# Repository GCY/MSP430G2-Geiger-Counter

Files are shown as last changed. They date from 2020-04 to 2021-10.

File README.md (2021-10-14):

# MSP430G2-Geiger-Counter

This device is Geiger-Muller Counter ,and True Random Number Generator(TRNG) uses radioactive isotopes.
</br>

Audi R8 (https://youtu.be/-gwNQ9MdoDw)

## Features

- [x] Radiation Detection - CPS, CPM, uSv/h, mSv/Y
- [x] Temperature - degree Celsius (°C)
- [x] True Random Number Generator - Serial Port Output 8bit TRNG





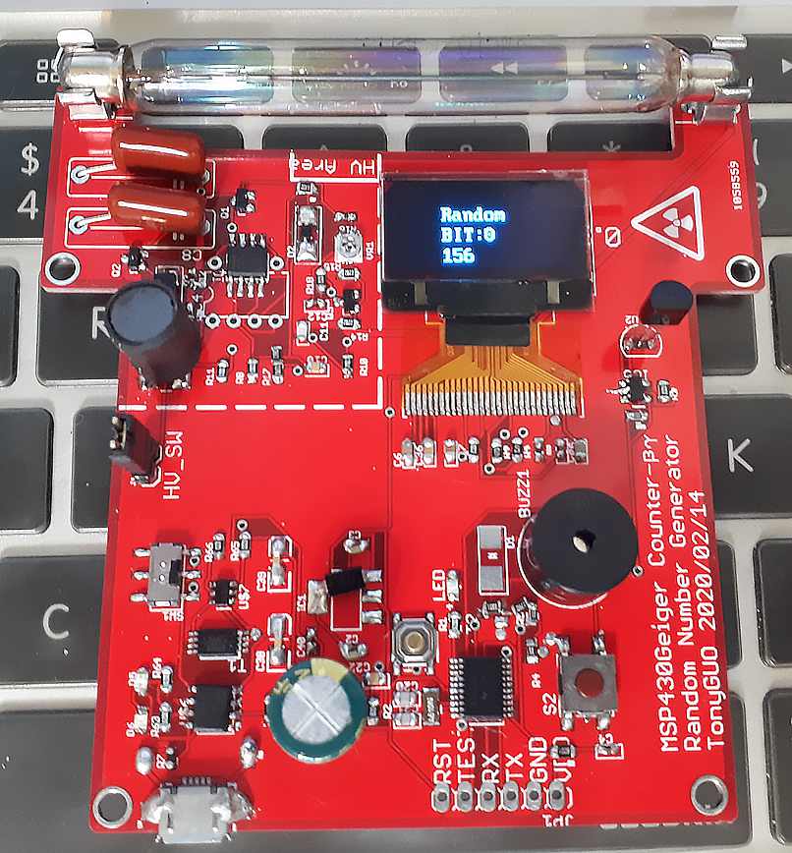
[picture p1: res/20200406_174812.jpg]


## Hardware

### Key Component List
- Geiger-Muller Tube - J321βγ, M4011, SBM-20...etc
- MSP430G2433 or MSP430G2553
- TLC555 (CMOS 555, DIP or SMD)
- TMP35 (Operate Voltage 3.3v)
- Fuse Holder on PCB for T5x20 Size * 2

### Configure

- J1 - CMOS555 4.2v power supply.
- VR1 - Adjust High-Voltage output 180VDC~500VDC, DMM setting 1000VDC internal resistance = 10M, if you measure tube voltage around 250VDC you're doing fine(real voltage 400VDC).
- IC1 - if this is use LDO, your temperature sensor power supply voltage = 2.9v-3v(TMP35), use forward voltage(VF) 0.5v diode,  temperature sensor power supply voltage = 3.7v-4v(LM35).

</br>

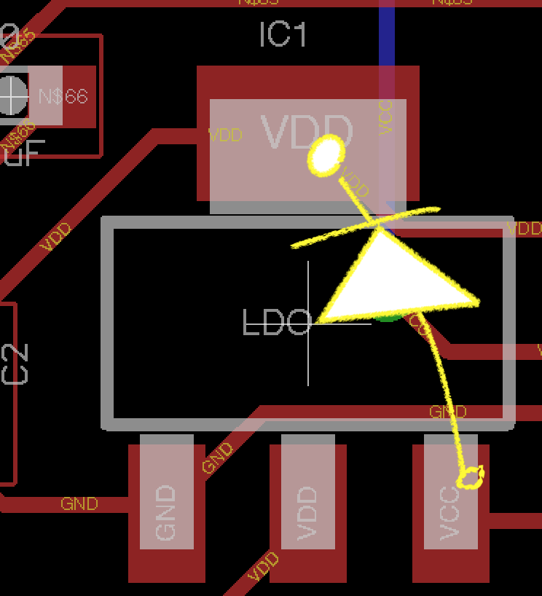
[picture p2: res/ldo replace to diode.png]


### Light Sensitive Problem (J321βγ, M4011)
[Reference This Discussion](http://www.gqelectronicsllc.com/forum/topic.asp?TOPIC_ID=4540)

</br>

For J321βγ, it doesn't happen often, I guess that's about wavelength of light.

## Firmware

### Build and Burn The .hex file
- Install Energia 1.6.10E18
- Select board -> MSP430G2553
- Open MSP430Geiger.ino
- Connect Debugger BSL to MSP430Geiger
- Upload
- Done

### Key Parameters

How to calculate calibration factor? Reference [Method1,2,3,4](https://sites.google.com/site/diygeigercounter/technical/gm-tubes-supported?authuser=0 ) (SBM-20 = 175, M4011 or J321βγ = 153.8)
</br>
<pre><code>
const float CPM2uSv = 153.8f; //CPM to uSv/h conversion rate
</code></pre>

</br>
R19, R20 is 10k and 33k, LM321 gain = 1+(33k/10k) = 4.3, so original temperature voltage: temp_vol = (ADC/4.3) * (3.3/1024), every 10mV(TMP35, LM35) = 1°C, temperature = temp_vol / 0.01 °C.
<pre><code>
const float TEMPERATURE_GAIN = 1.0f + 3.3f; // 1+ (33k/10k)
const float ADC2VOL = (3.3f/1024.0f);  // 3.3v/10bit
</code></pre>

### Radiation Measurements
If detected ionizing radiation MSP430G4 P1_4 interrupt count += 1.
</br>
CPM_TIME_PERIOD 20-second sampling-rate for count-per-minute calculate, CPM = 60sec/20sec * count;
<pre><code>
const unsigned long CPM_TIME_PERIOD = 20;
</code></pre>
Next, converting CPM to a Dose Unit.
<pre><code>
uSv/h = CPM / CPM2uSv(153.8);
mSv/Y = uSv/h * 24(Day-Hour) * 365(Year-Day)
</code></pre>
The worldwide average natural dose to humans is about 2.4 mSv/Y.

### Geiger Counter TRNG Algorithm

Calculate pulse-to-pulse time period of every three counts, if (C2-C1) > (C3-C2) output current bit 0 value, (C2-C1) <= (C3-C2) output current bit 1 value, this process is physically random.

<pre><code>
/* pseudo code */
pulse_diff_time_array[3] = {C1,C2,C3};

T1 = C2-C1;
T2 = C3-C2;

if(T1 > T2){
  random_number |= (0 <<= random_number_size);
}
if(T1 <= T2){
  random_number |= (1 <<= random_number_size);
}
++random_number_size;

if(random_number_size == 8){
  Serial Output random_number;
  random_number = 0;
  random_number_size = 0;
}

</code></pre>
</br>

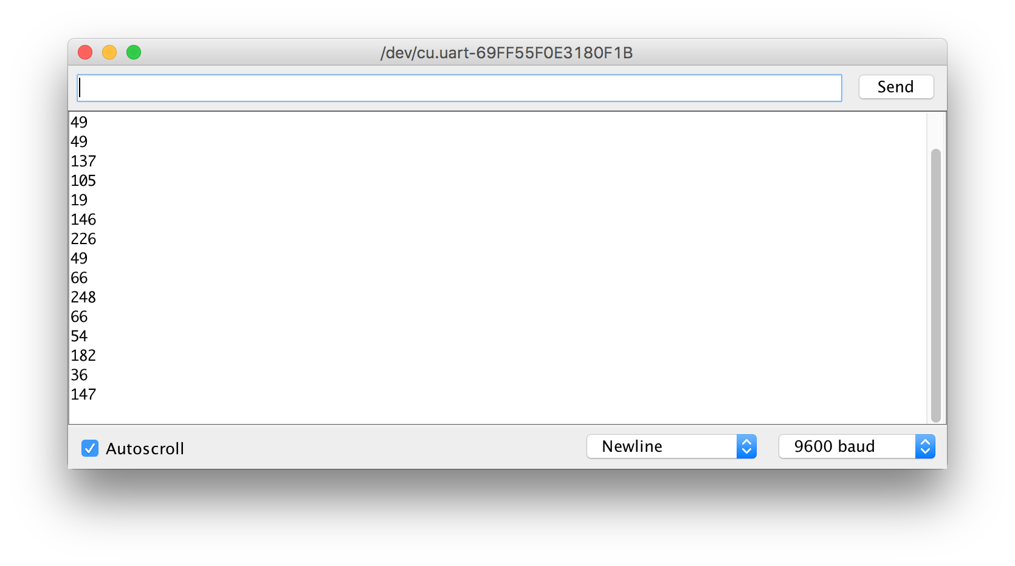
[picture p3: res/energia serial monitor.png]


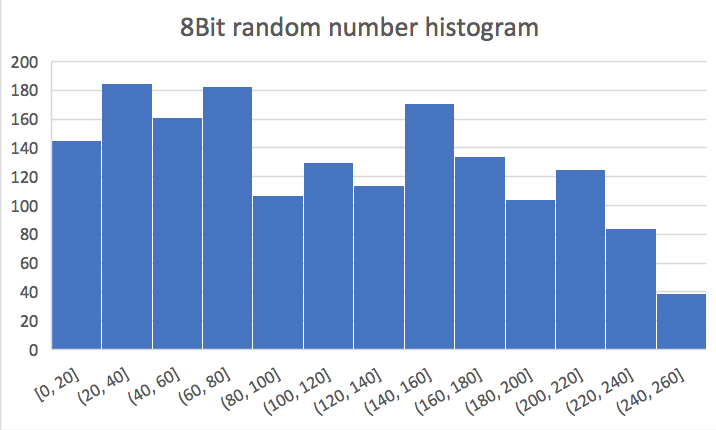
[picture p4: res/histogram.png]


### Encrypt Software Demo

## Reference

- [DIYGeiger](https://sites.google.com/site/diygeigercounter)
- [Geiger Counter WiKi](https://en.wikipedia.org/wiki/Geiger_counter)
- [Hardware Random Number Generator](https://en.wikipedia.org/wiki/Hardware_random_number_generator)

LICENSE
-------

MIT License

Copyright (c) 2020 Tony Guo https://github.com/GCY

Permission is hereby granted, free of charge, to any person obtaining a copy
of this software and associated documentation files (the "Software"), to deal
in the Software without restriction, including without limitation the rights
to use, copy, modify, merge, publish, distribute, sublicense, and/or sell
copies of the Software, and to permit persons to whom the Software is
furnished to do so, subject to the following conditions:

The above copyright notice and this permission notice shall be included in all
copies or substantial portions of the Software.

THE SOFTWARE IS PROVIDED "AS IS", WITHOUT WARRANTY OF ANY KIND, EXPRESS OR
IMPLIED, INCLUDING BUT NOT LIMITED TO THE WARRANTIES OF MERCHANTABILITY,
FITNESS FOR A PARTICULAR PURPOSE AND NONINFRINGEMENT. IN NO EVENT SHALL THE
AUTHORS OR COPYRIGHT HOLDERS BE LIABLE FOR ANY CLAIM, DAMAGES OR OTHER
LIABILITY, WHETHER IN AN ACTION OF CONTRACT, TORT OR OTHERWISE, ARISING FROM,
OUT OF OR IN CONNECTION WITH THE SOFTWARE OR THE USE OR OTHER DEALINGS IN THE
SOFTWARE.

OSHW Certification
-------

https://certification.oshwa.org/tw000004.html

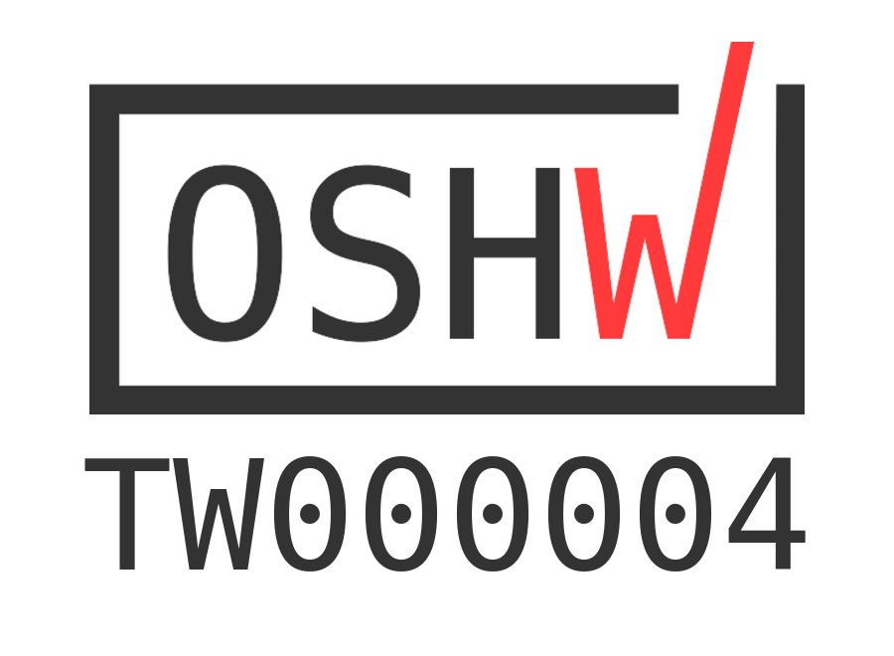
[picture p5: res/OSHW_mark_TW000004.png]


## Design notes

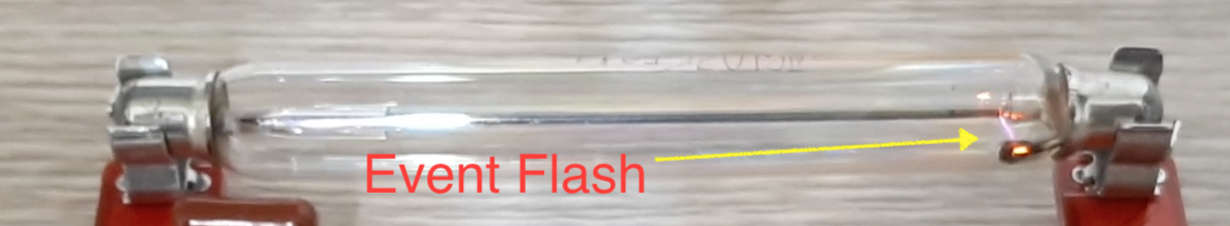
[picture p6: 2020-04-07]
res/geiger-muller tube flash.png

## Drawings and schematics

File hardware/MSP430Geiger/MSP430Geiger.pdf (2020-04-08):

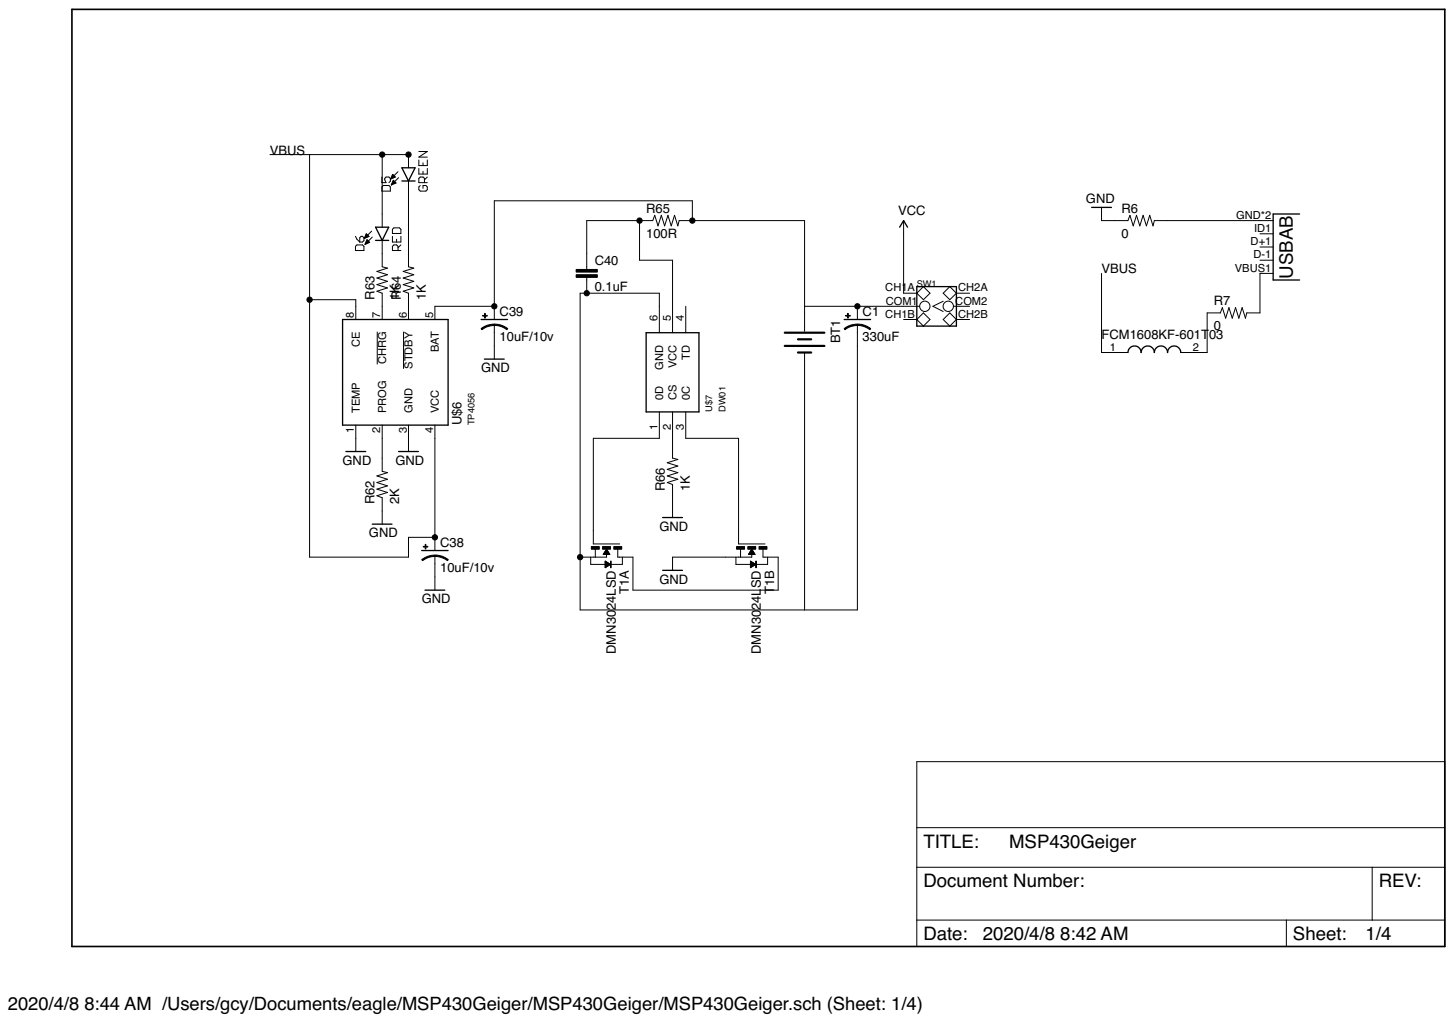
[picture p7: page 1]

Document Number: | REV:

Date: 2020/4/8 8:42 AM | Sheet: 1/4

2020/4/8 8:44 AM /Users/gcy/Documents/eagle/MSP430Geiger/MSP430Geiger/MSP430Geiger.sch (Sheet: 1/4)

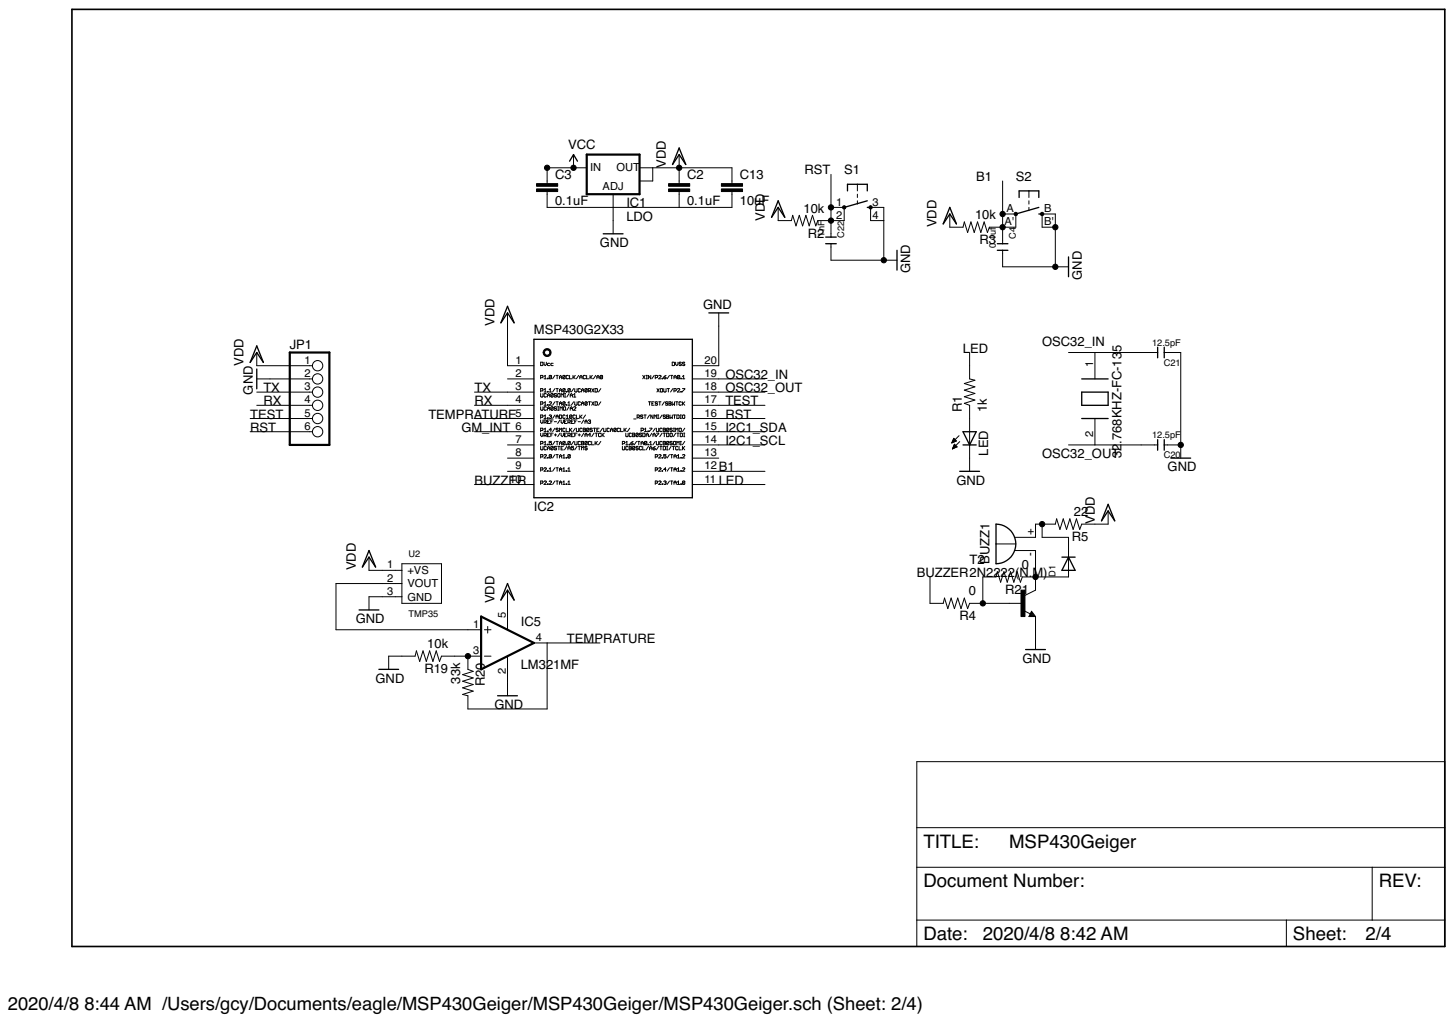
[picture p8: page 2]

Document Number: | REV:

Date: 2020/4/8 8:42 AM | Sheet: 2/4

2020/4/8 8:44 AM /Users/gcy/Documents/eagle/MSP430Geiger/MSP430Geiger/MSP430Geiger.sch (Sheet: 2/4)

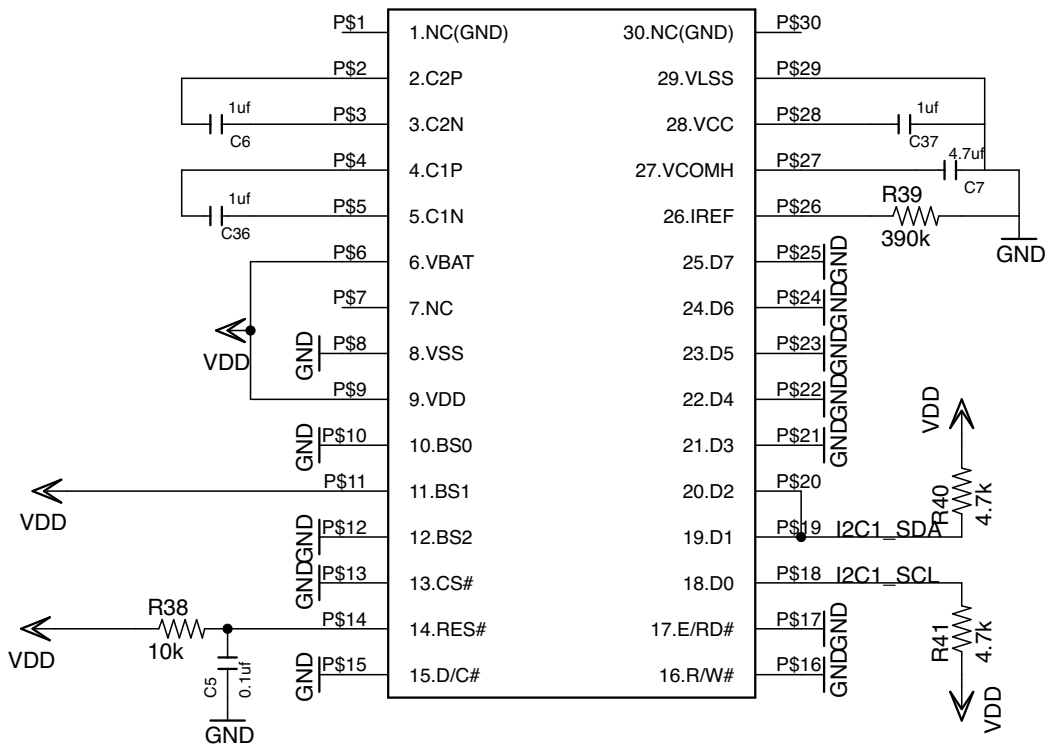
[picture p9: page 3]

GND GND GND GND GND

Document Number: | REV:

Date: 2020/4/8 8:42 AM | Sheet: 3/4

2020/4/8 8:44 AM /Users/gcy/Documents/eagle/MSP430Geiger/MSP430Geiger/MSP430Geiger.sch (Sheet: 3/4)

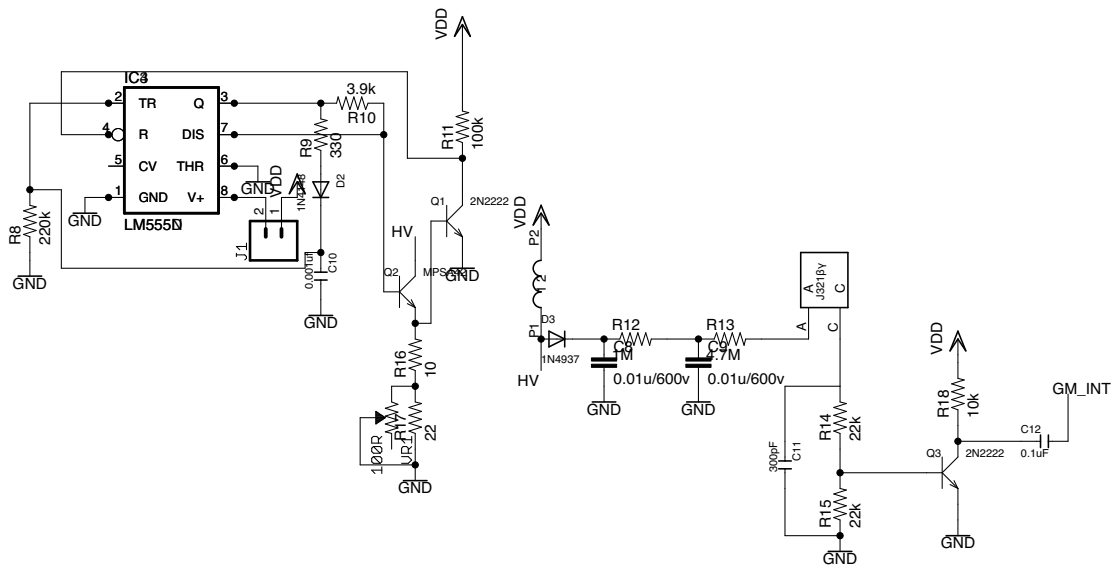
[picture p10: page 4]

Document Number: | REV:

Date: 2020/4/8 8:42 AM | Sheet: 4/4

2020/4/8 8:44 AM /Users/gcy/Documents/eagle/MSP430Geiger/MSP430Geiger/MSP430Geiger.sch (Sheet: 4/4)

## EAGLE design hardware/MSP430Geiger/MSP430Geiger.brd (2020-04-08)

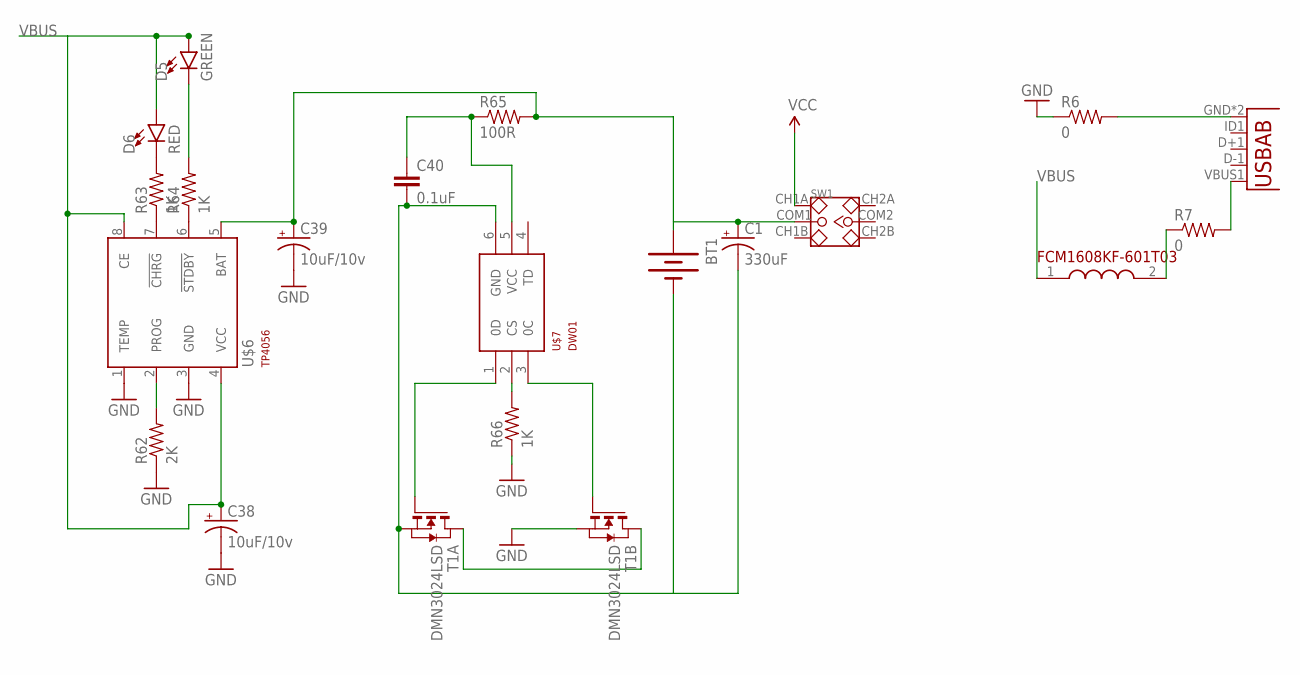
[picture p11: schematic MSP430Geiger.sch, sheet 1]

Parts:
BT1: BATTERYLIPO-TABS; LIPO-110-TABS
C1: 330uF; E3,5-8
C38, C39: 10uF/10v; EIA3216-KIT
C40: 0.1uF; 0603-CAP
D5: GREEN; LED-0603
D6: RED; LED-0603
R6, R7: 0; 0805
R62: 2K; 0603-RES
R63, R64, R66: 1K; 0603-RES
R65: 100R; 0603-RES
SW1: SMD-TOGGLE-SWITCH-2CH(2X3P-7X3.5MM); SW6-2.54-SMD-7.0X3.5X1.5MM
T1: DMN3024LSD; TSSOP-8
U1: USB""; USB-MICRO-SMD
U$4: FCM1608KF-601T03
U$6: TP4056; SOT23-8
U$7: DW01; SOT23-6

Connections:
GND: C38.C (-), C39.C (-), R6.1, R62.1, R66.1, T1.6 (S), T1.7 (S), U$6.1 (TEMP), U$6.3 (GND); also elsewhere on the board
unnamed: R7.2, U1.VBUS1 (VBUS)
unnamed: BT1.+, C1.+, C39.A (+), R65.2, SW1.COM1, U$6.5 (BAT)
unnamed: R7.1, U$4.2 (2.OUT)
unnamed: R6.2, U1.GND, U1.GND1 (GND)
unnamed: R62.2, U$6.2 (PROG)
unnamed: R63.1, U$6.7 (!CHRG)
unnamed: R64.1, U$6.6 (!STDBY)
unnamed: D6.C, R63.2
unnamed: D5.C, R64.2
unnamed: C40.1, R65.1, U$7.5 (VCC)
unnamed: BT1.-, C1.-, C40.2, T1.2 (S), T1.3 (S), U$7.6 (GND)
unnamed: T1.4 (G), U$7.1 (0D)
unnamed: R66.2, U$7.2 (CS)
unnamed: T1.1 (D), T1.8 (D)
unnamed: T1.5 (G), U$7.3 (0C)
VBUS: C38.A (+), D5.A, D6.A, U$4.1 (1.IN), U$6.4 (VCC), U$6.8 (CE)
VCC: SW1.CH1A; also elsewhere on the board

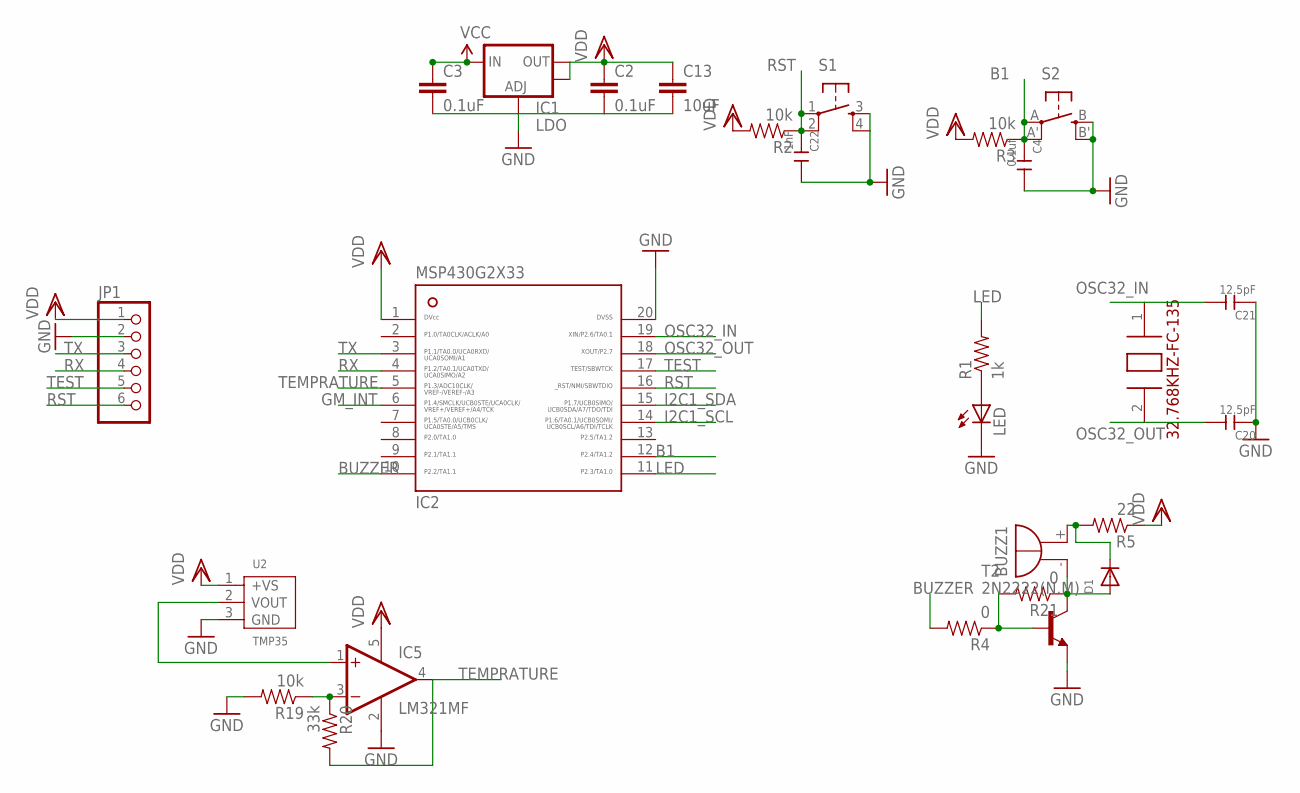
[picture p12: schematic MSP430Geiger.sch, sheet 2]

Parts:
BUZZ1: F/QMBIII
C2, C3: 0.1uF; 0603-CAP
C4: 0.1uf; C0603
C13: 10uF; 0603-CAP
C20, C21: 12.5pF; C0603
C22: 1nF; C0603
D1: DIODESMA; SMADIODE
IC1: LDO; SOT223
IC2: MSP430; PW20
IC5: LM321MF; SOT23-5
JP1: PINHD-1X6; 1X06
LED: LEDCHIP-LED0805; CHIP-LED0805
R1: 1k; 0805
R2, R3: 10k; 0603
R4, R21: 0; 0805
R5: 22; 0805
R19: 10k; 0805
R20: 33k; 0805
S1: TAC_SWITCHSMD; TACTILE_SWITCH_SMD
S2: SPST_TACT-EVQQ2; EVQ-Q2
T2: 2N2222(N.M); SOT23-EBC
U2: TMP35; TO-92-3
U$8: 32.768KHZ-FC-135

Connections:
B1: C4.1, IC2.12, R3.1, S2.A, S2.A' (P1)
BUZZER: IC2.10, R4.2
GM_INT: IC2.6; also elsewhere on the board
GND: C2.2, C3.2, C4.2, C13.2, C20.1, C21.1, C22.2, IC1.1 (ADJ), IC2.20, IC5.2 (V-), JP1.2, LED.C, R19.2, S1.3, S1.4, S2.B (S), S2.B' (S1), T2.E, U2.3 (GND); also elsewhere on the board
I2C1_SCL: IC2.14; also elsewhere on the board
I2C1_SDA: IC2.15; also elsewhere on the board
LED: IC2.11, R1.2
unnamed: R4.1, R21.2, T2.B
unnamed: LED.A, R1.1
unnamed: BUZZ1.- (+), D1.A, R21.1, T2.C
unnamed: BUZZ1.+ (-), D1.C, R5.2
unnamed: IC5.3 (-IN), R19.1, R20.1
unnamed: IC5.1 (+IN), U2.2 (VOUT)
OSC32_IN: C21.2, IC2.19, U$8.1 (1.XIN)
OSC32_OUT: C20.2, IC2.18, U$8.2 (2.XIN)
RST: C22.1, IC2.16, JP1.6, R2.1, S1.1, S1.2
RX: IC2.4, JP1.4
TEMPRATURE: IC2.5, IC5.4 (OUT), R20.2
TEST: IC2.17, JP1.5
TX: IC2.3, JP1.3
VCC: C3.1, IC1.3 (IN); also elsewhere on the board
VDD: C2.1, C13.1, IC1.2 (OUT), IC1.4 (OUT), IC2.1, IC5.5 (V+), JP1.1, R2.2, R3.2, R5.1, U2.1 (+VS); also elsewhere on the board

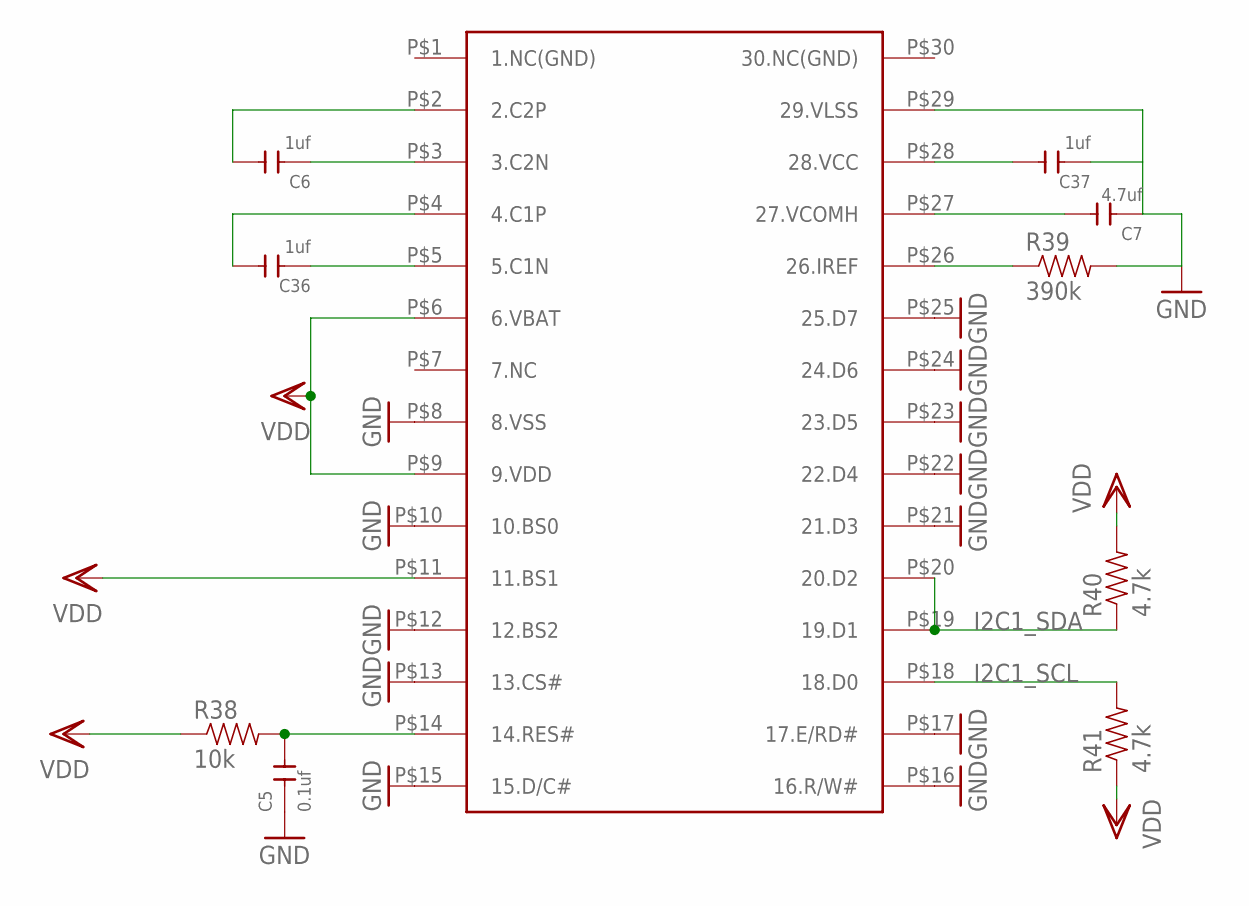
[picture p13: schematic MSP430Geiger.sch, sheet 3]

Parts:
C5: 0.1uf; C0603
C6, C36, C37: 1uf; C0603
C7: 4.7uf; C0603
R38: 10k; 0603
R39: 390k; 0603
R40, R41: 4.7k; 0603
U$18: ER-OLED0.96

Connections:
GND: C5.1, C7.1, C37.1, R39.2, U$18.P$8 (8.VSS), U$18.P$10 (10.BS0), U$18.P$12 (12.BS2), U$18.P$13 (13.CS#), U$18.P$15 (15.D/C#), U$18.P$16 (16.R/W#), U$18.P$17 (17.E/RD#), U$18.P$21 (21.D3), U$18.P$22 (22.D4), U$18.P$23 (23.D5), U$18.P$24 (24.D6), U$18.P$25 (25.D7), U$18.P$29 (29.VLSS); also elsewhere on the board
I2C1_SCL: R41.2, U$18.P$18 (18.D0); also elsewhere on the board
I2C1_SDA: R40.1, U$18.P$19 (19.D1), U$18.P$20 (20.D2); also elsewhere on the board
unnamed: C5.2, R38.2, U$18.P$14 (14.RES#)
unnamed: C6.1, U$18.P$3 (3.C2N)
unnamed: C36.1, U$18.P$5 (5.C1N)
unnamed: C6.2, U$18.P$2 (2.C2P)
unnamed: C36.2, U$18.P$4 (4.C1P)
unnamed: R39.1, U$18.P$26 (26.IREF)
unnamed: C7.2, U$18.P$27 (27.VCOMH)
unnamed: C37.2, U$18.P$28 (28.VCC)
VDD: R38.1, R40.2, R41.1, U$18.P$6 (6.VBAT), U$18.P$9 (9.VDD), U$18.P$11 (11.BS1); also elsewhere on the board

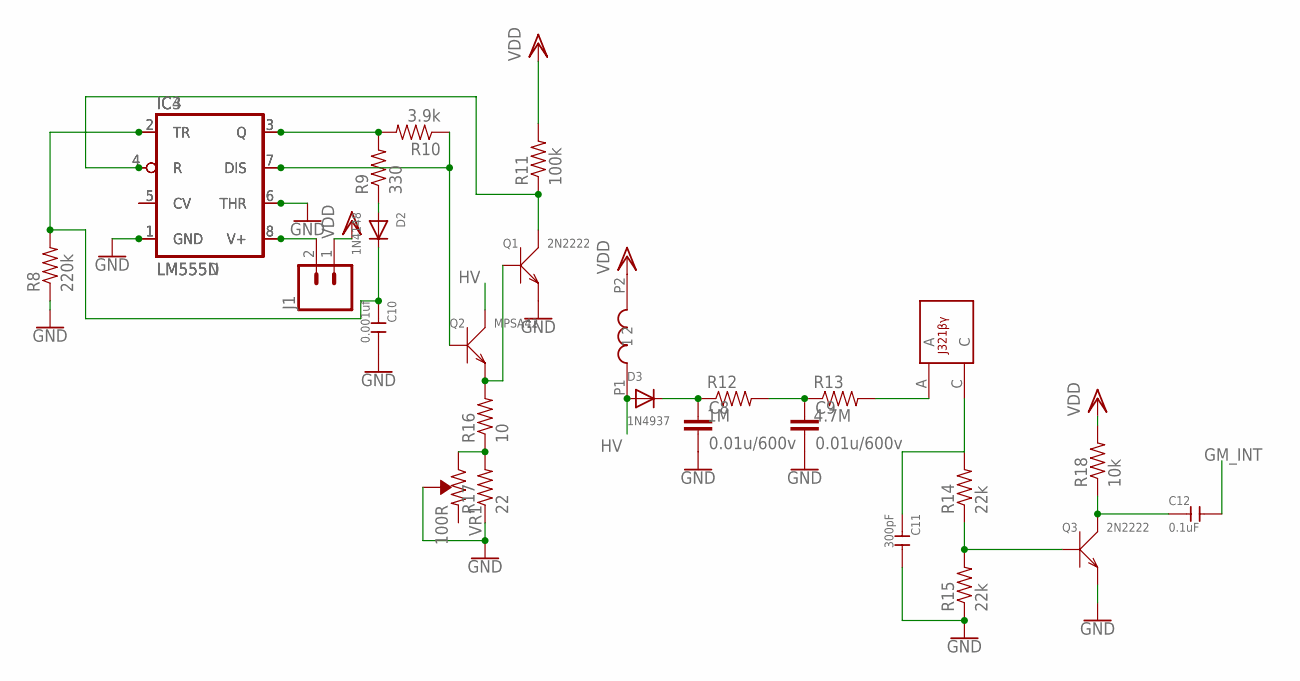
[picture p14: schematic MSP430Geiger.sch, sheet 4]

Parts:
C8, C9: 0.01u/600v; C15B5
C10: 0.001uf; C0603
C11: 300pF; C0603
C12: 0.1uF; C0603
D2: 1N4148; SMADIODE
D3: 1N4937; SMADIODE
IC3: LM555D; SO08
IC4: LM555N; DIL08-ROUND
J1: CONN_02; 1X02
Q1, Q3: 2N2222; SOT-23
Q2: MPSA42; SOT-23
R8: 220k; 0603
R9: 330; 0603
R10: 3.9k; 0603
R11: 100k; 0603
R12: 1M; 0603
R13: 4.7M; 0603
R14, R15: 22k; 0603
R16: 10; 0603
R17: 22; 0603
R18: 10k; 0603
U$1: J321βγ
U$2: 10mF; CD54
VR1: 100R; TRIMPOT-SMD-3MM-CLOSED

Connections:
GM_INT: C12.2; also elsewhere on the board
GND: C8.2, C9.2, C10.2, C11.2, IC3.1 (GND), IC3.6 (THR), IC4.1 (GND), IC4.6 (THR), Q1.2 (E), Q3.2 (E), R8.1, R15.1, R17.1, VR1.2 (WIPER); also elsewhere on the board
HV: D3.A, Q2.3 (C), U$2.P1 (1)
unnamed: IC3.3 (Q), IC4.3 (Q), R9.2, R10.2
unnamed: D2.A, R9.1
unnamed: IC3.7 (DIS), IC4.7 (DIS), Q2.1 (B), R10.1
unnamed: C10.1, D2.C, IC3.2 (TR), IC4.2 (TR), R8.2
unnamed: IC3.4 (R), IC4.4 (R), Q1.3 (C), R11.1
unnamed: Q1.1 (B), Q2.2 (E), R16.2
unnamed: C8.1, D3.C, R12.1
unnamed: C9.1, R12.2, R13.1
unnamed: R16.1, R17.2, VR1.3 (CW)
unnamed: IC3.5 (CV), IC4.5 (CV)
unnamed: R13.2, U$1.A
unnamed: C11.1, R14.2, U$1.C
unnamed: Q3.1 (B), R14.1, R15.2
unnamed: IC3.8 (V+), IC4.8 (V+), J1.2
unnamed: C12.1, Q3.3 (C), R18.1
VDD: J1.1, R11.2, R18.2, U$2.P2 (2); also elsewhere on the board

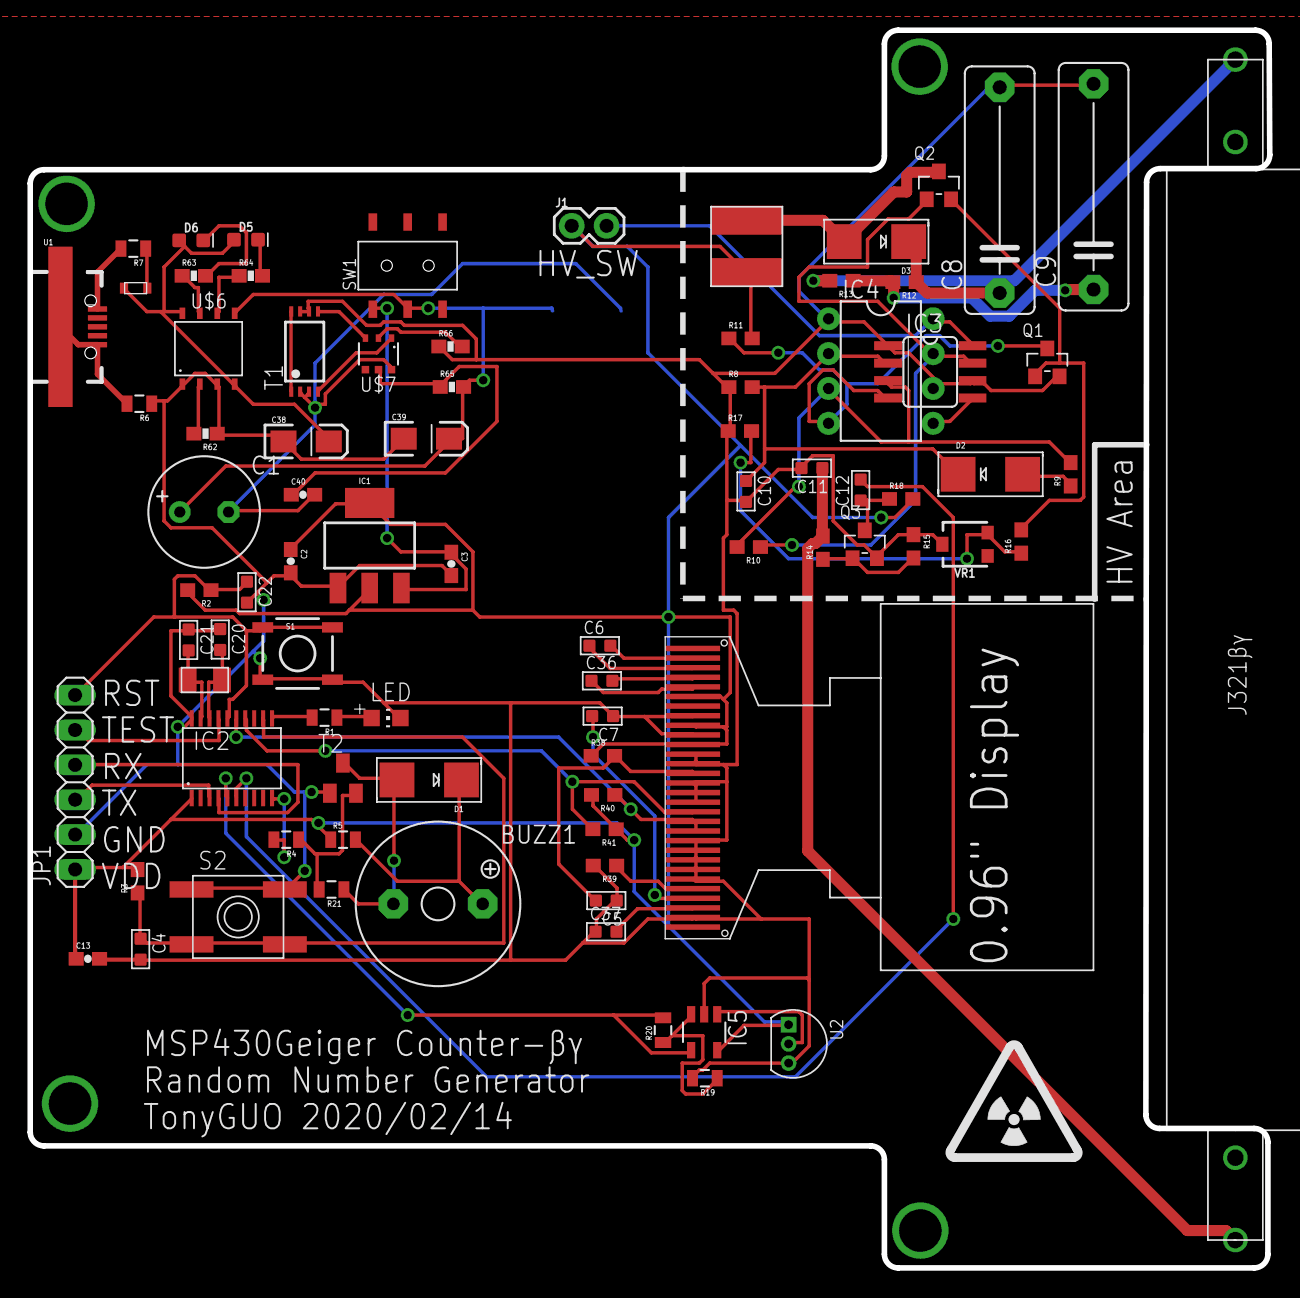
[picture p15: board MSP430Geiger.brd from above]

Board: 2 copper layers, 90.3 x 90.2 mm, 85 parts (1 on the bottom side), 62 nets.

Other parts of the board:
U$3: RADIOACTIVE_10.00

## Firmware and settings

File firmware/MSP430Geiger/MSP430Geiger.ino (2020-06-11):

#include "ASCII_CODE_8X16_5X8_VERTICAL.H"

#include <Wire.h>

#define OUTPUT_RNG_SERIAL

#define TMP35 P1_3
#define GEIGER_INT P1_4
#define B1 P2_4
#define BUZZER P2_2
#define LED P2_3

const uint8_t STRING_SIZE = 17;

const uint8_t BRIGHT = 0xFF;
const uint8_t DARK = 0x00;

const unsigned long SENCOND = 1000000;  // us
const uint16_t SENCOND_60 = 60; // minute
const uint16_t HOUR_24 = 24;  // day
const uint16_t DAY_365 =365;  // year

static const float ADC2VOL = (3.3f/1024.0f);  // 3.3v/10bit
const float TEMPERATURE_GAIN = 1.0f + 3.3f; // 1+ (33k/10k)
const float TEMPERATURE_CALIBRATION = 0;  // temperature offset deg_C;
const float TEMPERATURE_ADC_SCALE = 1000.0f;
static unsigned long temperature_update_time = 0;
const unsigned int TEMPERATURE_SAMPLING_RATE = 50000; // 50000us = 20Hz
static unsigned long sampling_update_time = 0;
double temp_sum = 0;
static unsigned int sampling_count = 0;

enum{
  GEIGER_COUNTER_MODE,
  TEMPERATURE_MODE,
  RANDON_NUMBER_GENERATOR_MODE
};
uint8_t mode = GEIGER_COUNTER_MODE;
bool switch_flag = false;

//const float CPM2uSv = 175.0f; //CPM to uSv/h conversion rate of SBM-20
const float CPM2uSv = 153.8f; //CPM to uSv/h conversion rate of M4011

static unsigned long usv_update_time = 0;
static unsigned long count = 0;

const unsigned long CLICK_TIME_PERIOD = 900;  // us, Geiger Tube Dead Time
static unsigned long click_time = 0;

const unsigned long DEAD_ZONE_PERIOD = 200;  // us, Geiger Tube Dead Zone
static unsigned long dead_zone_time = 0;

static bool count_flag = false;

static unsigned long last_pulse_time = 0;
const uint8_t PULSE_ARRAY_SIZE = 3;
unsigned long pulse_diff_time_array[PULSE_ARRAY_SIZE];
unsigned long pulse_count = 0;
uint8_t random_number = 0;
uint8_t random_number_size = 0;

const unsigned long CPS_TIME_PERIOD = 1;  // Count per Second, unit uSv/h, 1-second count
const unsigned long CPM_TIME_PERIOD = 20; // Count per Minute, unit mSv/Y, count * 60/20 = CPM
static unsigned long cps_update_time = 0;

unsigned char address = 0x3C; // SSD1306 I2C Address

static const uint8_t init_command[] = {
  0xae,
  0xd5,0x80,
  0xa8,0x3f,
  0xd3,0x00,
  0x40,
  0x8d,0x14,
  0x20,0x02,
  0xc8,0xa1,
  0xda,0x12,
  0x81,0xcf,
  0xd9,0xf1,
  0xdb,0x40,
  0xa6,
  0xaf
};

void TransCommand(uint8_t command)
{
  Wire.beginTransmission(address);
  Wire.write(0x00);
  Wire.write(command);
  Wire.endTransmission();
}

void TransData(uint8_t data)
{
  Wire.beginTransmission(address);
  Wire.write(0x40);
  Wire.write(data);
  Wire.endTransmission();
}

void InitSSD1306()
{
  
  for(int i = 0;
  i < (sizeof(init_command) / sizeof(uint8_t));++i){
    TransCommand(init_command[i]);
  }
  
  //byte error = Wire.endTransmission();  
}

void LCMMemoryAddress(uint8_t page,uint8_t column)
{
  column = column - 1;
  page = page - 1;
  TransCommand(0xb0 + page);
  TransCommand(((column>>4) & 0x0f) + 0x12);
  TransCommand(column&0x0f); 
}

void FullDisplay(uint8_t data1)
{
  for(int i = 0;i < 8;++i){
    LCMMemoryAddress(i + 1,1);
    for(int j = 128 - 1;j >= 0;--j){
      TransData(data1);
    }
  }
}

void StringDataWrite(uint8_t page,uint8_t column,char *text)
{
  if(column > 128){
    column = 1;
    page += 2;
  }
  uint8_t i = 0,j = 0;  
  while(text[i] > 0x00){ 
    if((text[i] >= 0x20) && (text[i] <= 0x7e)){
      j = text[i] - 0x20;
      for(uint8_t n = 0;n < 2;++n){     
        LCMMemoryAddress(page + n,column);
        for(uint8_t k = 0;k < 8;++k){         
          TransData(ascii_table_8x16[j][k + (8 * n)]);
        }
      }
      ++i;
      column += 8;
    }
    else{
      ++i;
    }    
  }
}

void DisplayString(uint8_t page,uint8_t column,char *text)
{
  char temp[2];
  uint8_t i = 0;
  while(text[i] != '\0'){
    temp[0] = text[i];    
    temp[1] = '\0';
    StringDataWrite(page, column, temp);
    column += 8;
    ++i;
  }
}

void GeigerDetected()
{
  detachInterrupt(GEIGER_INT);
  count_flag = true;  
  ++count;
  //attachInterrupt(P1_4,func2,RISING);
}

void ModeSet()
{
  detachInterrupt(B1);
  mode += 1;
  mode %= 3;  
  //attachInterrupt(B1,ModeSet,FALLING);

  switch_flag = true;
}

void Set32_768KHz()
{
  BCSCTL1 &=~ XT2OFF;

  do{
    IFG1 &=~ OFIFG;
    for(uint8_t a = 0xFF;a > 0;--a);
  }
  while((IFG1 & OFIFG));
  BCSCTL3 |= LFXT1S_0 + XCAP_3;
  while(IFG1 & OFIFG){
    IFG1 &= ~OFIFG;
  }  
}

void setup() {

  Set32_768KHz();

  pinMode(LED,OUTPUT);
  digitalWrite(LED,LOW);   
  pinMode(BUZZER,OUTPUT);
  digitalWrite(BUZZER,HIGH);   
  
#ifdef OUTPUT_RNG_SERIAL
  Serial.begin(9600);
  Serial.println("MSP430Geiger");
#endif  

  pinMode(GEIGER_INT,INPUT);
  attachInterrupt(GEIGER_INT,GeigerDetected,FALLING);
  
  pinMode(B1,INPUT);
  attachInterrupt(B1,ModeSet,FALLING);

  
  Wire.setModule(0); 
  Wire.begin();

  InitSSD1306();

  FullDisplay(DARK);  
  
  FullDisplay(BRIGHT);
  delay(1000);
  FullDisplay(DARK);  
  DisplayString(2,1,"TonyGuo");
  DisplayString(4,1,"Ver 1.0");
  DisplayString(6,1,"2020/02/14");
  delay(1000);
  FullDisplay(DARK);  
  DisplayString(2,1,"MSP430G2");
  DisplayString(4,1,"GeigerCount");
  DisplayString(6,1,"RNG");
  delay(1800);
  FullDisplay(DARK);  

  temperature_update_time = micros();
  usv_update_time = micros();
  cps_update_time = micros();
  click_time = micros();
  dead_zone_time = micros();

}

void loop() {
  
  if(count_flag && ((micros() - dead_zone_time) > DEAD_ZONE_PERIOD) ){
    count_flag = false;
    click_time = micros();
    dead_zone_time = micros();
    attachInterrupt(GEIGER_INT,GeigerDetected,FALLING);
  }
  
  if(mode != RANDON_NUMBER_GENERATOR_MODE){
    if((micros() - click_time) < CLICK_TIME_PERIOD){
      digitalWrite(LED,HIGH);
      digitalWrite(BUZZER, LOW);
    }
    else{
      digitalWrite(LED,LOW); 
      digitalWrite(BUZZER,HIGH);    
    }
  }

  if(mode == GEIGER_COUNTER_MODE){

    if(switch_flag){
      detachInterrupt(GEIGER_INT);
      
      FullDisplay(DARK);  
      switch_flag = false;
      
      count = 0;
      usv_update_time = micros();
      
      attachInterrupt(B1,ModeSet,FALLING);
      attachInterrupt(GEIGER_INT,GeigerDetected,FALLING);            
    }
    
    if((micros() - usv_update_time) > CPM_TIME_PERIOD * SENCOND){
      detachInterrupt(GEIGER_INT);
      
      digitalWrite(LED,LOW); 
      digitalWrite(BUZZER,HIGH);  
        
      usv_update_time = micros();
  
      char str[STRING_SIZE]="";
      sprintf(str,"CPM:%d     ",count*(SENCOND_60/CPM_TIME_PERIOD));   
      DisplayString(1,1,str);

      float uSv = ((count*(SENCOND_60/CPM_TIME_PERIOD))*1000)/CPM2uSv;
      if(uSv < 100){
        sprintf(str,"uSv/h:0.0%ld   ",(unsigned long)uSv);
      }
      else if(uSv < 1000){
        sprintf(str,"uSv/h:0.%ld   ",(unsigned long)uSv);
      }
      else{
        float dot_uSv = uSv - (1000*(unsigned long)(uSv/1000));
        sprintf(str,"uSv/h:%ld.%ld   ",(unsigned long) uSv/1000,(unsigned long) dot_uSv);
      }

      DisplayString(3,1,str); 

      uSv /= 1000;
      float mSv = uSv * HOUR_24 * DAY_365;
      float dot_mSv = mSv - (1000*(unsigned long)(mSv/1000));
      sprintf(str,"mSv/Y:%ld.%ld   ",(unsigned long) mSv/1000,(unsigned long) dot_mSv);
      DisplayString(5,1,str); 
  
      count = 0;

      attachInterrupt(GEIGER_INT,GeigerDetected,FALLING);
    }
    else if((micros() - cps_update_time) > CPS_TIME_PERIOD * SENCOND)/* if( (micros() - count_time) < 1000)*/{
      detachInterrupt(GEIGER_INT);
      
      digitalWrite(LED,LOW); 
      digitalWrite(BUZZER,HIGH);    
      
      char str[STRING_SIZE]={""};
      sprintf(str,"CPS:%ld   ",count);
      //inttostr(str,count);
      //DisplayString(7,1,"CPS: ");
      DisplayString(7,1,str);
      cps_update_time = micros();

      attachInterrupt(GEIGER_INT,GeigerDetected,FALLING);
    }
  }
  else if(mode == TEMPERATURE_MODE){
    if(switch_flag){
      FullDisplay(DARK);  
      switch_flag = false;

      temp_sum = 0;
      sampling_count = 0;

      attachInterrupt(B1,ModeSet,FALLING);
    }
    
    if((micros() - sampling_update_time) > TEMPERATURE_SAMPLING_RATE){
      float temp = (analogRead(TMP35) * ADC2VOL) / TEMPERATURE_GAIN;
      temp_sum += temp;
      ++sampling_count;
      sampling_update_time = micros();
    }    
    
    if((micros() - temperature_update_time) > SENCOND){
      detachInterrupt(GEIGER_INT);
 
      temp_sum /= sampling_count;
      temp_sum += TEMPERATURE_CALIBRATION;
      temp_sum *= TEMPERATURE_ADC_SCALE;
      char str[STRING_SIZE]={""};
      //sprintf(str,"Temp:%ld.%ldC",(unsigned long)(temp/10),(unsigned long)(temp-(10*(unsigned long)(temp/10))));
      sprintf(str,"Temp:%ld.%ldC",(unsigned long)(temp_sum/10),(unsigned long)(temp_sum-(10*(unsigned long)(temp_sum/10))));
      DisplayString(5,1,str);

      temp_sum = 0;
      sampling_count = 0;
      
      temperature_update_time = micros(); 

      attachInterrupt(GEIGER_INT,GeigerDetected,FALLING);
     }
  }
  else if(mode == RANDON_NUMBER_GENERATOR_MODE){
    if(switch_flag){
      FullDisplay(DARK);  
      switch_flag = false;    
      attachInterrupt(B1,ModeSet,FALLING);  
    }    
    if(click_time != last_pulse_time){
      unsigned long diff_time = click_time - last_pulse_time;
      last_pulse_time = click_time;
      ++pulse_count;
      pulse_diff_time_array[pulse_count%PULSE_ARRAY_SIZE] = diff_time;
      if(pulse_count > PULSE_ARRAY_SIZE){
        unsigned long T1 = pulse_diff_time_array[(pulse_count-1)%PULSE_ARRAY_SIZE] - pulse_diff_time_array[(pulse_count-2)%PULSE_ARRAY_SIZE];
        unsigned long T2 = pulse_diff_time_array[(pulse_count-2)%PULSE_ARRAY_SIZE] - pulse_diff_time_array[(pulse_count-3)%PULSE_ARRAY_SIZE];
        uint8_t b = 0;
        if(T1 > T2){
          DisplayString(5,1,"BIT:0");
          b = 0;
        }
        else if(T1 <= T2){
          DisplayString(5,1,"BIT:1");
          b = 1;
        }
        random_number |= (b <<= random_number_size);
        ++random_number_size;
        if(random_number_size == 8){
          
          char str[STRING_SIZE]="";
          sprintf(str,"%d  ",random_number);   
          DisplayString(7,1,str); 

#ifdef OUTPUT_RNG_SERIAL
          Serial.println(str);
#endif
          
          random_number = 0;
          random_number_size = 0;
        }
      }
      /*
      char str[STRING_SIZE]="";
      sprintf(str,"%ldms  ",(unsigned long)(diff_time/1000));   
      DisplayString(4,1,str);      
      sprintf(str,"%ldus  ",diff_time);   
      DisplayString(6,1,str);
      */
      DisplayString(3,1,"Random");
      //cps_update_time = micros();
    }
  }
  
}

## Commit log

2020-03-27 Eagle PCB V1.1
    [MSP430Geiger.brd, MSP430Geiger.sch]
2020-04-06 TRGN File
    [TRNG result.xlsx]
2020-04-07 calibration factor

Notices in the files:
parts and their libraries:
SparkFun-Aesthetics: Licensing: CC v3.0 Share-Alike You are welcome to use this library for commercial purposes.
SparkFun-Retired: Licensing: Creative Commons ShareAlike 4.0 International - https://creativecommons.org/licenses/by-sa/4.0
